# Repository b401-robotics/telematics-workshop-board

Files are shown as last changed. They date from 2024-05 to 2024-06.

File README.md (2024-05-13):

<!-- center -->
<h1 align="center">Telematics Workshop Board</h1>

<p align="center">
	</a>
	</a>
	</a>
</p>

This repository contains the documentation for the Workshop Telematics Board. The board is based on the ESP8266 microcontroller and has several features that can be used for various projects.

<!-- beritahu versi lawas -->
> For the previous version of the board, refer to the [v1 board.](https://github.com/b401-robotics/esp8266-minsys)

## 🌟 Features

The following are the features available on this board.

- ESP-12F (ESP8266)
- 8 GPIO Pins
- Programmable RGB LED
- Overcurrent Protection
- USB Type-C Connector (_Power Delivery Support_) 

## 👀 Preview

Here is a preview of the board that will be used in the workshop.

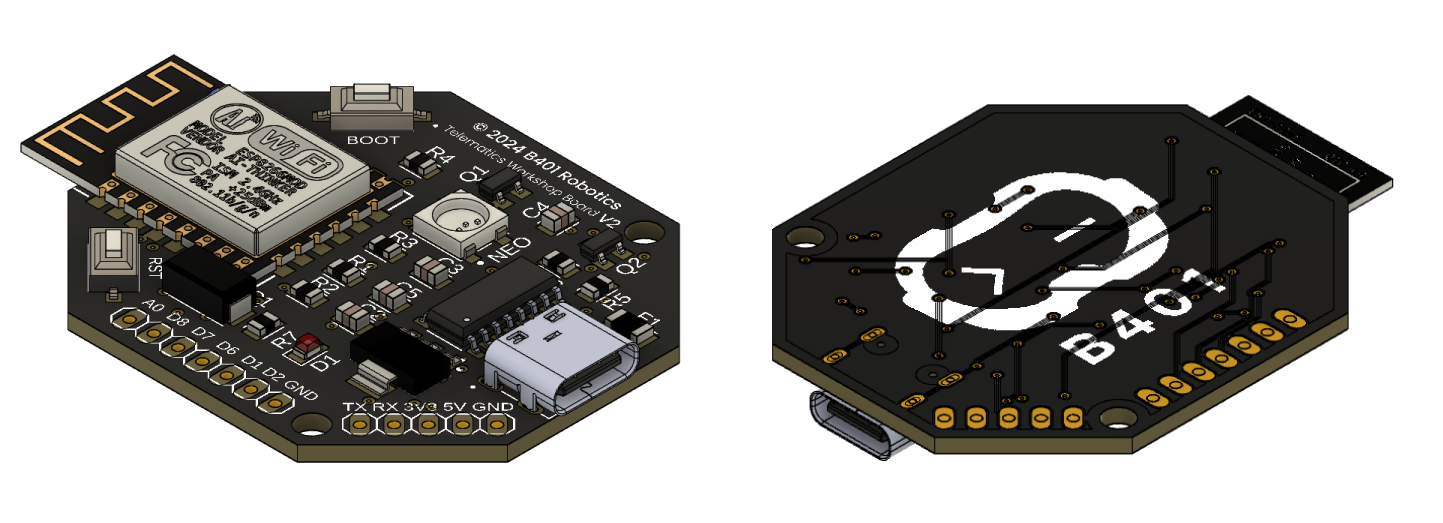
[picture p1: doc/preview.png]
Board Preview


## 📚 Resources

For more information about the board, you can check the following resources.

- [Hardware](hardware/)
- [Firmware](firmware/)

## 🔮 Project Showcase

Discover projects that use this board in various applications and contexts.

- [🌌 __COMING SOON__]() by [farisrfp](https://farisrfp.me)

## 📝 License

Distributed under the MIT License. See `LICENSE` for more information.

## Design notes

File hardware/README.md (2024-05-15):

# **Hardware**

This folder contains the hardware design for the Telematics Workshop Board.

## 🚀 Getting Started

### Prerequisites

- [Eagle](https://www.autodesk.com/products/eagle/overview) 
- [Fusion 360](https://www.autodesk.com/products/fusion-360/overview)

## 🕸 Schematic

This is the schematic diagram for the Board will be used in the workshop.

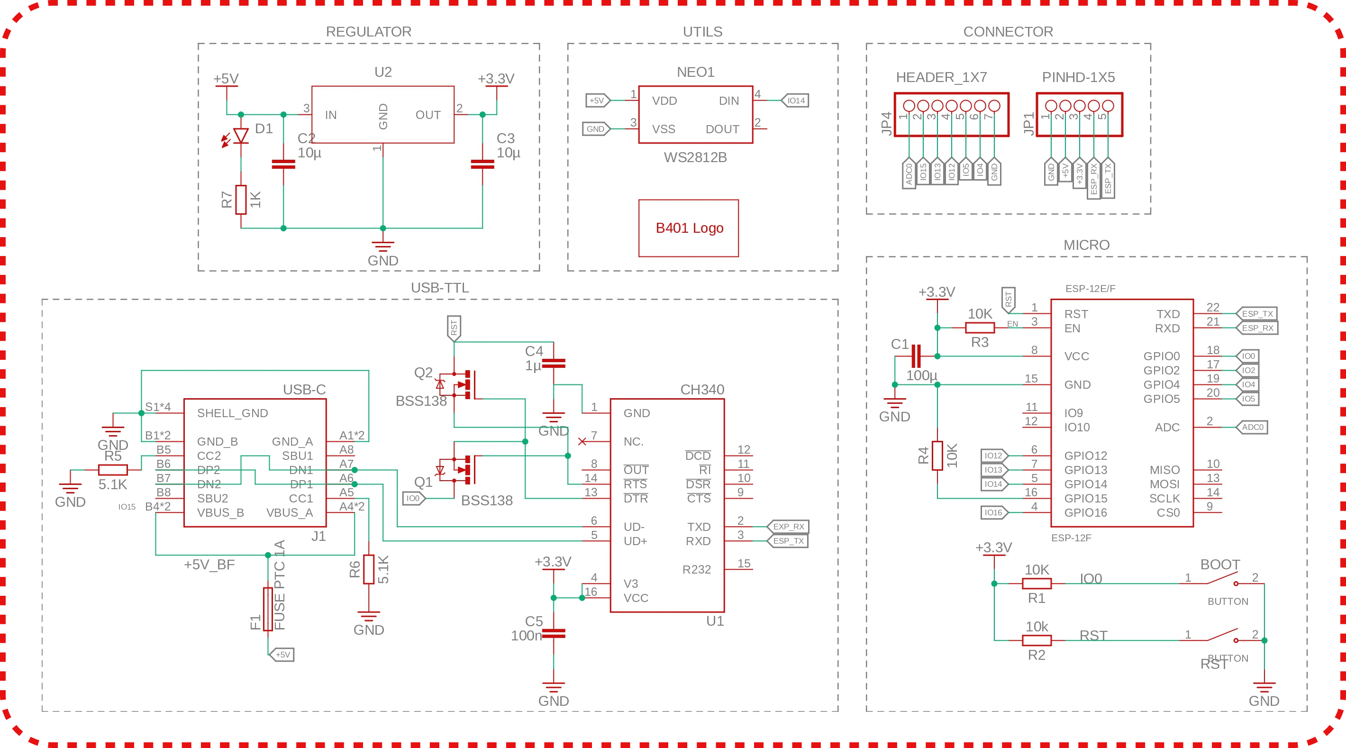
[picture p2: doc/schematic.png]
Schematic


## 💲 Bill of Material

| Designator | Quantity | Package  | Value  | Description |
|:---:|:---:|:---:|:---:|:---:|
| ESP-12F | 1 | - | - | ESP8266 Module |
| U1 | 1 |  SOP-16  | CH340C | IC USB to UART |
| U2 | 1 | SOT-223  |  3V3 | Voltage Regulator 3V3 |
| D1 | 1 | 0805 |  Red | LED |
| NEO | 1 | 5050 |  RGB | WS2812B |
| F1 | 1 | 1206 | 750mA  | Resettable Fuse |
| J1 | 1 | - |  16P | USB Type-C |
| BOOT, RST | 2 | - | - | Push Button |
| R1, R2, R3, R4 | 4 | 0805 |  10K | Resistor |
| R5, R6 | 2 | 0805 |  5.1K  | Resistor |
| R7 | 1 | 0805 | 1K | Resistor |
| C1 | 1 | 2412 |  100u  | Capacitor (Polar) |
| C2, C3 | 2 | 0805 |  10u | Capacitor (Nonpolar)  |
| C4 | 1 | 0805 | 1u | Capacitor (Nonpolar)  |
| C5 | 1 | 0805 |  10n | Capacitor (Nonpolar)  |
| Q1, Q2 | 2 |  SOT-23  | BSS138 | N-Channel MOSFET |

## 👨‍🔧 PCB Assembly

Refer to the image below for detailed placement and routing.

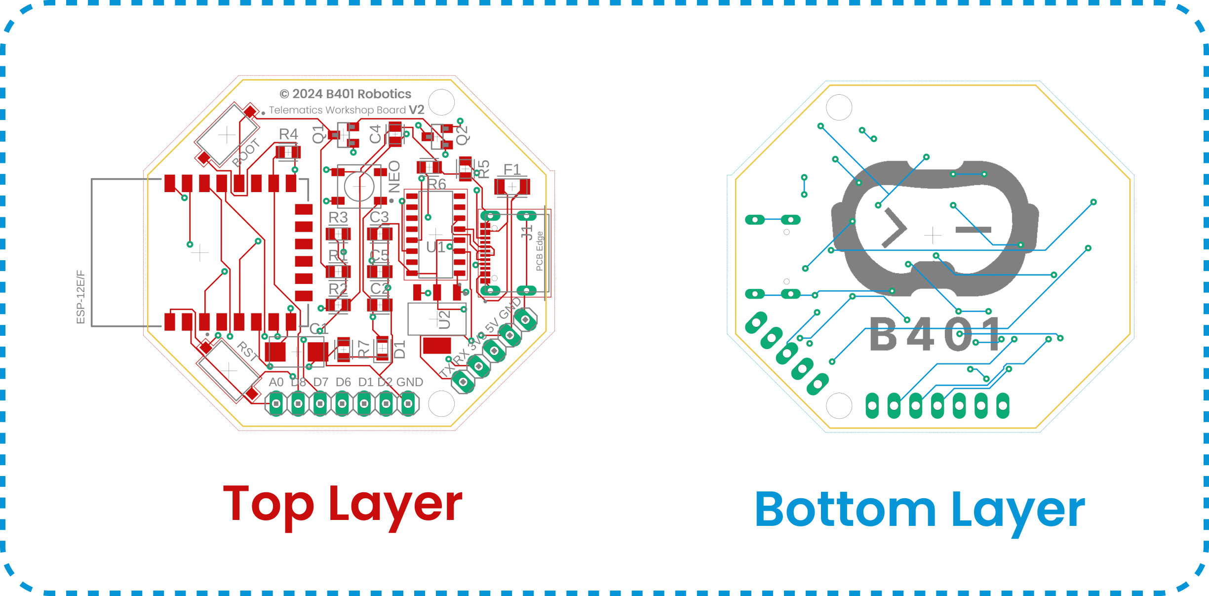
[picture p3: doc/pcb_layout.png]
PCB Layout


> Click the image to view the full resolution.

### SMD Polarity

SMD LEDs have 2 pins, namely the anode and cathode pins. Refer to the image below to determine which pin is the anode and cathode.

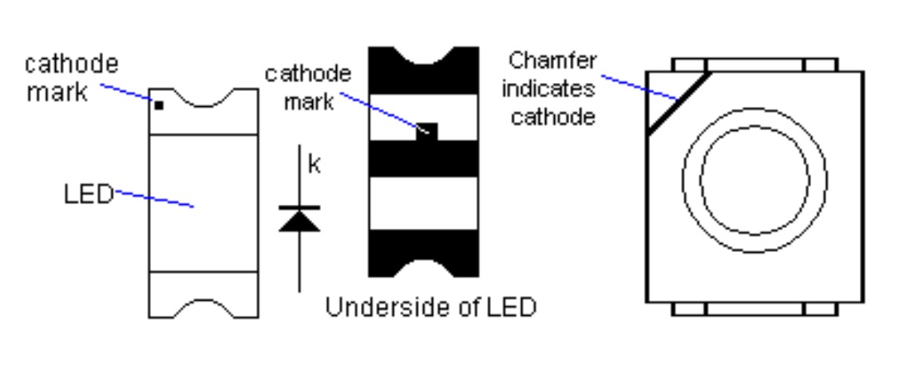
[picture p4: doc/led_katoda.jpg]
SMD Led Polarity


The Tantalum Capacitor is one of the polar capacitors. Refer to the image below to determine which pin is the anode(+).

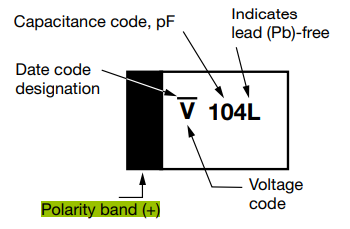
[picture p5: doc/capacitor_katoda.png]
Capacitor Tantalum Polarity


## 📚 Resources

### Telematics Workshop Board

Access the design files for the Telematics Workshop Board directly from this repository:

- [Schematic](./telematics_board_v2.sch)
- [Board Design](./telematics_board_v2.brd)
- [3D Model](./telematics_board_v2.step)
- [Eagle/Fusion 360 Library](libraries/)

### Enclosure

Access the 3D printable enclosure files from this repository, with contributions from the following individuals:

- [B401 Robotics]()

<!-- ## SMD Polarity

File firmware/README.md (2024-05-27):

# **Firmware**

This folder contains the firmware for the Telematics Workshop Board. The firmware is based on the ESP8266 microcontroller and uses the Arduino framework for development.

## 🚀 Getting Started

### Prerequisites

- [PlatformIO](https://platformio.org/)
- [Visual Studio Code](https://code.visualstudio.com/)

### Dependencies

- [💡 FastLED]()
- [👆 EasyButton]()

### Installation

1. Clone the repo
   ```sh
   git clone
   ```
2. Open the firmware folder and open the project in Visual Studio Code
   ```sh
   cd firmware
   code .
   ```
3. Build and upload the firmware to the board

##

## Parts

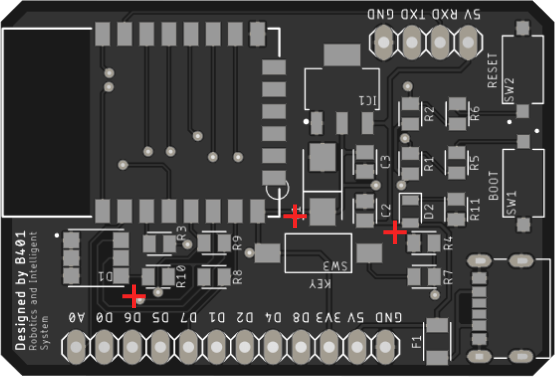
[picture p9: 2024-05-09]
doc/polar_component.png

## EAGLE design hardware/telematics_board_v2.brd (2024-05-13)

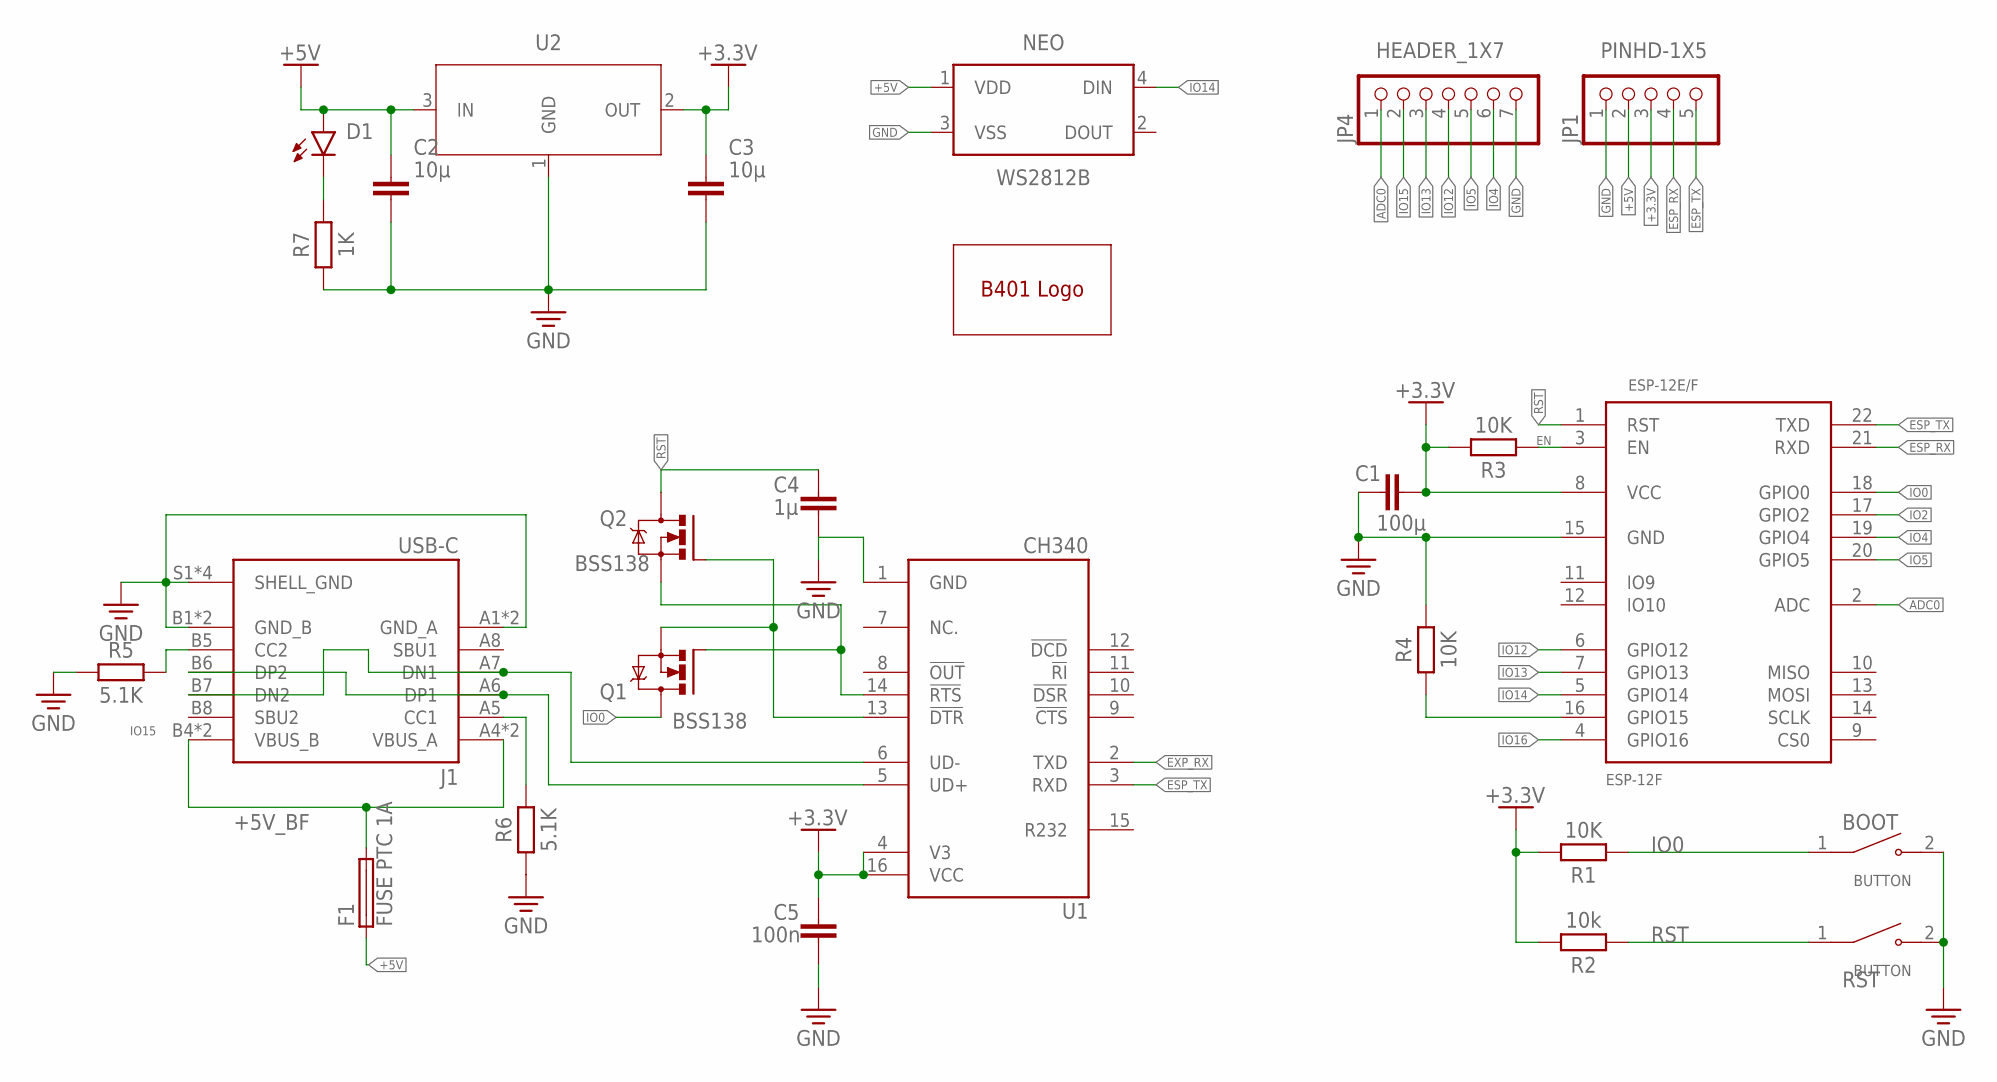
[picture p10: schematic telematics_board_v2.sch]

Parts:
BOOT: BUTTON; SWITCH-2P
C1: 100µ; CAPM6032X280
C2, C3: 10µ; CAPC2012X110
C4: 1µ; CAPC2012X110
C5: 100n; CAPC2012X110
D1: LED_RED; LEDC2012X110N_FLAT-R
ESP-12E/F: ESP-12F
F1: FUSE PTC 1A; FUSC3215X82N
J1: USB-C; USB-C-16P
JP1: PINHD-1X5; 1X05
JP4: HEADER_1X7; 1X07
NEO: WS2812B
Q1, Q2: BSS138; SOT23
R1, R3, R4: 10K; RESC2012X65
R2: 10k; RESC2012X65
R5, R6: 5.1K; RESC2012X65
R7: 1K; RESC2012X65
RST: BUTTON; SWITCH-2P
U1: CH340; SOIC127P600X180-16N
U2: NCP1117ST33T3G; SOT230P700X170-4
U$1: LOGO_B401LARGE; B401_LARGE

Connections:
+3.3V: C1.2, C3.1, C5.1, ESP-12E/F.8 (VCC), JP1.3, R1.2, R2.2, R3.2, U1.4 (V3), U1.16 (VCC), U2.2 (OUT)
+5V: C2.1, D1.A, F1.1, JP1.2, NEO.1 (VDD), U2.3 (IN)
+5V_BF: F1.2, J1.A4 (VBUS_A), J1.A9 (VBUS_A), J1.B4 (VBUS_B), J1.B9 (VBUS_B)
ADC0: ESP-12E/F.2 (ADC), JP4.1
EN: ESP-12E/F.3 (EN), R3.1
ESP_RX: ESP-12E/F.21 (RXD), JP1.4
ESP_TX: ESP-12E/F.22 (TXD), JP1.5, U1.3 (RXD)
EXP_RX: U1.2 (TXD)
GND: BOOT.2, C1.1, C2.2, C3.2, C4.2, C5.2, ESP-12E/F.15 (GND), J1.A1 (GND_A), J1.A12 (GND_A), J1.B1 (GND_B), J1.B12 (GND_B), J1.S1 (SHELL_GND), J1.S2 (SHELL_GND), J1.S3 (SHELL_GND), J1.S4 (SHELL_GND), JP1.1, JP4.7, NEO.3 (VSS), R4.2, R5.1, R6.1, R7.1, RST.2, U1.1 (GND), U2.1 (GND)
IO0: BOOT.1, ESP-12E/F.18 (GPIO0), Q1.3 (D), R1.1
IO2: ESP-12E/F.17 (GPIO2)
IO4: ESP-12E/F.19 (GPIO4), JP4.6
IO5: ESP-12E/F.20 (GPIO5), JP4.5
IO12: ESP-12E/F.6 (GPIO12), JP4.4
IO13: ESP-12E/F.7 (GPIO13), JP4.3
IO14: ESP-12E/F.5 (GPIO14), NEO.4 (DIN)
IO15: ESP-12E/F.16 (GPIO15), JP4.2, R4.1
IO16: ESP-12E/F.4 (GPIO16)
unnamed: J1.A6 (DP1), J1.B6 (DP2), U1.5 (UD+)
unnamed: J1.A7 (DN1), J1.B7 (DN2), U1.6 (UD-)
unnamed: Q1.2 (S), Q2.1 (G), U1.13 (!DTR)
unnamed: J1.B5 (CC2), R5.2
unnamed: J1.A5 (CC1), R6.2
unnamed: Q1.1 (G), Q2.2 (S), U1.14 (!RTS)
unnamed: D1.C, R7.2
RST: C4.1, ESP-12E/F.1 (RST), Q2.3 (D), R2.1, RST.1

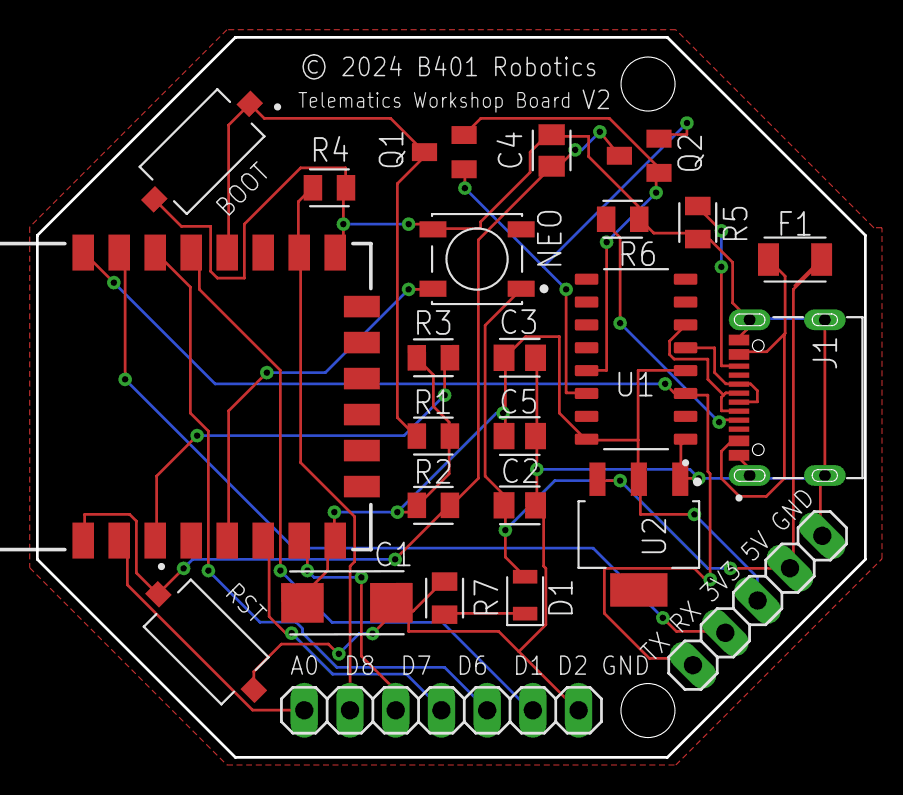
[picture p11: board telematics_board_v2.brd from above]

Board: 2 copper layers, 46.0 x 40.0 mm, 26 parts (1 on the bottom side), 23 nets.

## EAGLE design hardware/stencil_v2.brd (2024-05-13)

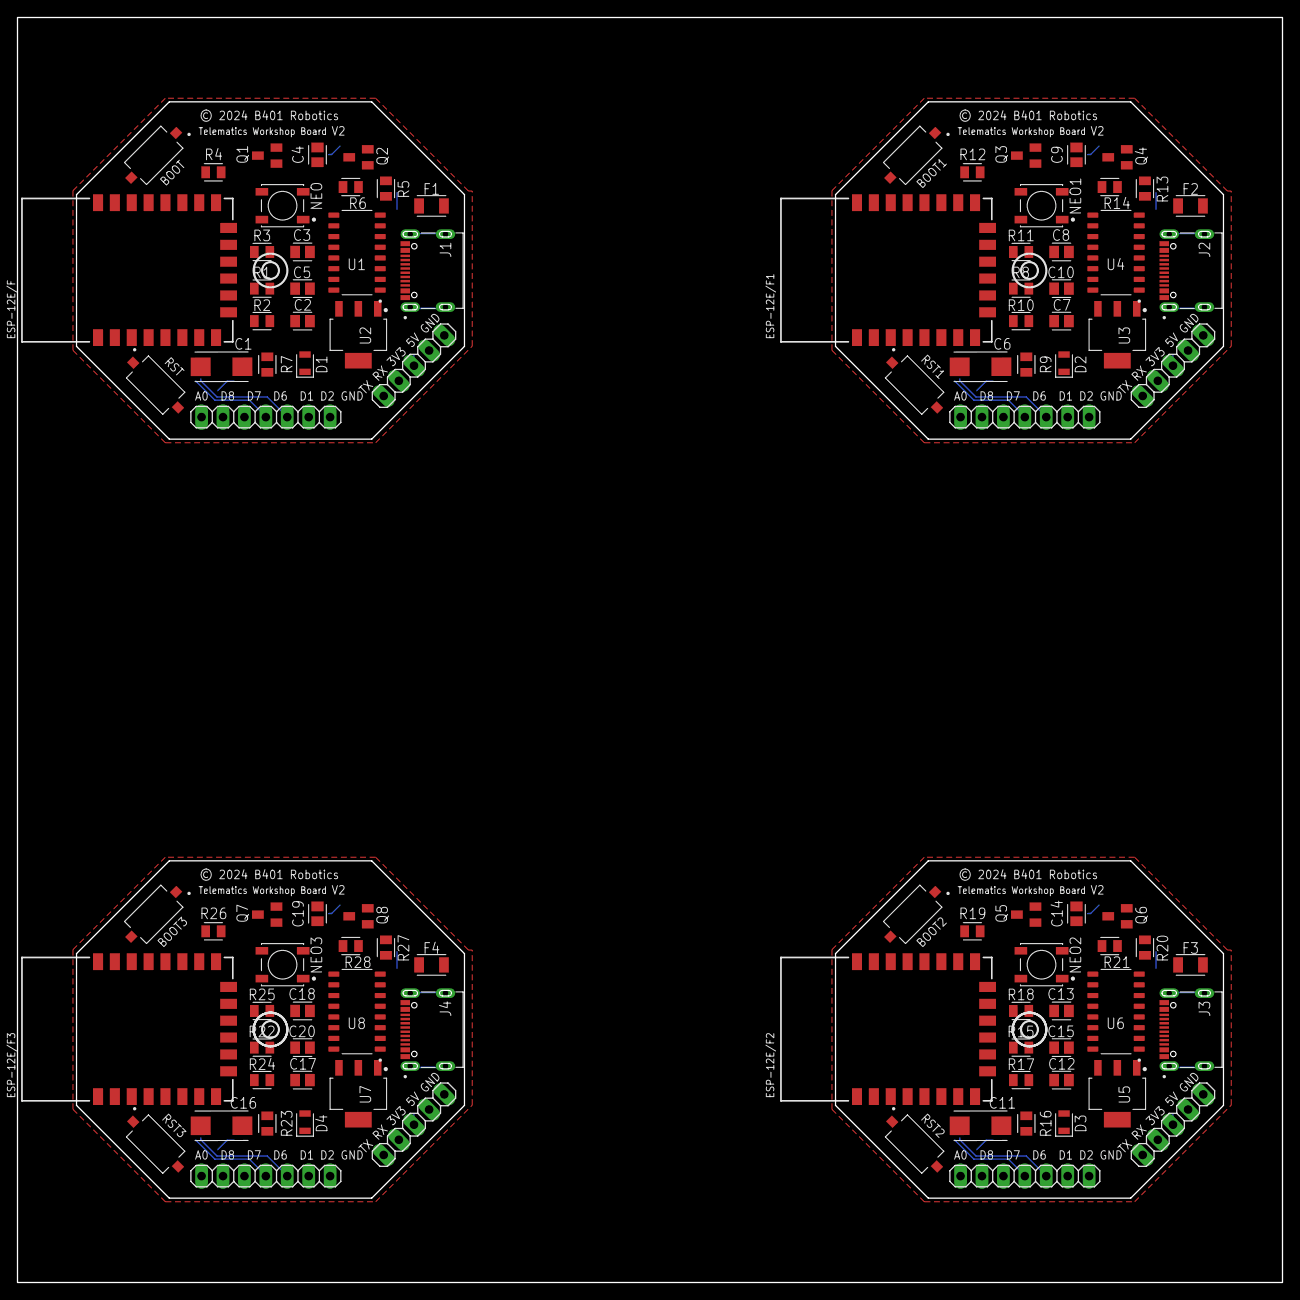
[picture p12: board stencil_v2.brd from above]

Board: 2 copper layers, 150.0 x 150.0 mm, 100 parts (0 on the bottom side), 88 nets.

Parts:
BOOT, BOOT1, BOOT2, BOOT3: BUTTON; SWITCH-2P
C1, C6, C11, C16: 100µ; CAPM6032X280
C2, C3, C7, C8, C12, C13, C17, C18: 10µ; CAPC2012X110
C4, C9, C14, C19: 1µ; CAPC2012X110
C5, C10, C15, C20: 100n; CAPC2012X110
D1, D2, D3, D4: LED_RED; LEDC2012X110N_FLAT-R
ESP-12E/F, ESP-12E/F1, ESP-12E/F2, ESP-12E/F3: ESP-12F
F1, F2, F3, F4: FUSE PTC 1A; FUSC3215X82N
J1, J2, J3, J4: USB-C; USB-C-16P
JP1, JP3, JP6, JP8: PINHD-1X5; 1X05
JP2, JP4, JP5, JP7: HEADER_1X7; 1X07
NEO, NEO1, NEO2, NEO3: WS2812B
Q1, Q2, Q3, Q4, Q5, Q6, Q7, Q8: BSS138; SOT23
R1, R3, R4, R8, R11, R12, R15, R18, R19, R22, R25, R26: 10K; RESC2012X65
R2, R10, R17, R24: 10k; RESC2012X65
R5, R6, R13, R14, R20, R21, R27, R28: 5.1K; RESC2012X65
R7, R9, R16, R23: 1K; RESC2012X65
RST, RST1, RST2, RST3: BUTTON; SWITCH-2P
U1, U4, U6, U8: CH340; SOIC127P600X180-16N
U2, U3, U5, U7: NCP1117ST33T3G; SOT230P700X170-4

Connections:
+3.3V: C3.1, C5.1, U1.4, U1.16, U2.2
+3.3V1: C8.1, C10.1, U3.2, U4.4, U4.16
+3.3V2: C13.1, C15.1, U5.2, U6.4, U6.16
+3.3V3: C18.1, C20.1, U7.2, U8.4, U8.16
+5V: F1.1, JP1.2
+5V1: F2.1, JP3.2
+5V2: F3.1, JP6.2
+5V3: F4.1, JP8.2
+5V_BF: F1.2, J1.A4, J1.A9, J1.B4, J1.B9
+5V_BF1: F2.2, J2.A4, J2.A9, J2.B4, J2.B9
+5V_BF2: F3.2, J3.A4, J3.A9, J3.B4, J3.B9
+5V_BF3: F4.2, J4.A4, J4.A9, J4.B4, J4.B9
ADC0: ESP-12E/F.2, JP4.1
ADC1: ESP-12E/F1.2, JP2.1
ADC2: ESP-12E/F2.2, JP5.1
ADC3: ESP-12E/F3.2, JP7.1
ESP_TX: JP1.5, U1.3
ESP_TX1: JP3.5, U4.3
ESP_TX2: JP6.5, U6.3
ESP_TX3: JP8.5, U8.3
GND: C4.2, J1.A1, J1.A12, J1.B1, J1.B12, J1.S1, J1.S2, J1.S3, J1.S4, JP1.1, NEO.3, R5.1, R6.1
GND1: C9.2, J2.A1, J2.A12, J2.B1, J2.B12, J2.S1, J2.S2, J2.S3, J2.S4, JP3.1, NEO1.3, R13.1, R14.1
GND2: C14.2, J3.A1, J3.A12, J3.B1, J3.B12, J3.S1, J3.S2, J3.S3, J3.S4, JP6.1, NEO2.3, R20.1, R21.1
GND3: C19.2, J4.A1, J4.A12, J4.B1, J4.B12, J4.S1, J4.S2, J4.S3, J4.S4, JP8.1, NEO3.3, R27.1, R28.1
IO0: BOOT.1, ESP-12E/F.18, Q1.3, R1.1
IO1: BOOT1.1, ESP-12E/F1.18, Q3.3, R8.1
IO3: ESP-12E/F1.6, JP2.4
IO12: ESP-12E/F.6, JP4.4
IO15: ESP-12E/F.16, JP4.2, R4.1
IO17: ESP-12E/F1.16, JP2.2, R12.1
IO18: BOOT2.1, ESP-12E/F2.18, Q5.3, R15.1
IO19: ESP-12E/F2.6, JP5.4
IO26: ESP-12E/F2.16, JP5.2, R19.1
IO27: BOOT3.1, ESP-12E/F3.18, Q7.3, R22.1
IO28: ESP-12E/F3.6, JP7.4
IO35: ESP-12E/F3.16, JP7.2, R26.1
unnamed: J1.A6, J1.B6, U1.5
unnamed: J1.A7, J1.B7, U1.6
unnamed: Q1.2, Q2.1
unnamed: J1.B5, R5.2
unnamed: D1.C, R7.2
unnamed: D2.C, R9.2
unnamed: J2.A6, J2.B6, U4.5
unnamed: J2.A7, J2.B7, U4.6
unnamed: Q3.2, Q4.1
unnamed: J2.B5, R13.2
unnamed: D3.C, R16.2
unnamed: J3.A6, J3.B6, U6.5
unnamed: J3.A7, J3.B7, U6.6
unnamed: Q5.2, Q6.1
unnamed: J3.B5, R20.2
unnamed: D4.C, R23.2
unnamed: J4.A6, J4.B6, U8.5
unnamed: J4.A7, J4.B7, U8.6
unnamed: Q7.2, Q8.1
unnamed: J4.B5, R27.2
RST: C4.1, Q2.3, R2.1
RST1: C9.1, Q4.3, R10.1
RST2: C14.1, Q6.3, R17.1
RST3: C19.1, Q8.3, R24.1
S$1: C1.2, ESP-12E/F.8
S$2: R1.2, R2.2, R3.2
S$4: C1.1, C2.2, C3.2, C5.2, JP4.7, R7.1, RST.2
S$5: U1.1, U2.1
S$6: BOOT.2, ESP-12E/F.15, R4.2
S$7: ESP-12E/F.1, RST.1
S$11: C2.1, D1.A, NEO.1
S$21: C6.2, ESP-12E/F1.8
S$22: R8.2, R10.2, R11.2
S$24: U3.1, U4.1
S$25: C6.1, C7.2, C8.2, C10.2, JP2.7, R9.1, RST1.2
S$26: BOOT1.2, ESP-12E/F1.15, R12.2
S$27: ESP-12E/F1.1, RST1.1
S$32: C7.1, D2.A, NEO1.1
S$41: C11.2, ESP-12E/F2.8
S$42: R15.2, R17.2, R18.2
S$44: U5.1, U6.1
S$45: C11.1, C12.2, C13.2, C15.2, JP5.7, R16.1, RST2.2
S$46: BOOT2.2, ESP-12E/F2.15, R19.2
S$47: ESP-12E/F2.1, RST2.1
S$52: C12.1, D3.A, NEO2.1
S$61: C16.2, ESP-12E/F3.8
S$62: R22.2, R24.2, R25.2
S$64: U7.1, U8.1
S$65: C16.1, C17.2, C18.2, C20.2, JP7.7, R23.1, RST3.2
S$66: BOOT3.2, ESP-12E/F3.15, R26.2
S$67: ESP-12E/F3.1, RST3.1
S$72: C17.1, D4.A, NEO3.1

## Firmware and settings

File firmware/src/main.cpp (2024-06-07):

/*
☲☲☲☲ GETTING STARTED CODE ☲☲☲☲

- This code is for Wortel Development Board V2.
- This code is for beginners who want to learn how to program Wortel Development Board.
- And guess what? It's compatible with both PlatformIO and Arduino IDE!
*/

#include <Arduino.h>     // Standard Arduino library
#include <EasyButton.h>  // Library for handling button press
#include <FastLED.h>     // Library for controlling RGB LED

/* Variable Declaration */
#define BUTTON_PIN 0  // Button Pin
#define LED_PIN D5    // RGB LED Pin
#define NUM_LEDS 1    // Number of RGB LED

CRGB leds[NUM_LEDS];            // RGB LED Array
EasyButton button(BUTTON_PIN);  // Button Object

/* Function Prototype */
void buttonPressed();        // Function to handle button press
void buttonLongPressed();    // Function to handle long press
void buttonDoubleClicked();  // Function to handle double click
void buttonTripleClicked();  // Function to handle triple click

void setup() {
    /* Initialize Serial Monitor */
    Serial.begin(115200);
    randomSeed(analogRead(A0));

    /* Initialize RGB LED */
    FastLED.addLeds<WS2812, LED_PIN, GRB>(leds, NUM_LEDS);

    /* Initialize Button */
    button.begin();
    button.onPressed(buttonPressed);
    button.onPressedFor(500, buttonLongPressed);
    button.onSequence(2, 500, buttonDoubleClicked);
    button.onSequence(3, 500, buttonTripleClicked);

    /* you can add your code here */
}

void loop() {
    button.read();  // Always read the button in the loop

    /* you can add your code here */
}

void buttonPressed() {
    Serial.printf("Button Pressed\n");

    /* Generate Random Color */
    leds[0] = CRGB(random(126), random(126), random(126));
    FastLED.show();
}

void buttonLongPressed() {
    Serial.printf("Button Long Pressed\n");

    leds[0] = CRGB::Red;
    FastLED.show();
}

void buttonDoubleClicked() {
    Serial.printf("Button Double Clicked\n");

    leds[0] = CRGB::Green;
    FastLED.show();
}

void buttonTripleClicked() {
    Serial.printf("Button Triple Clicked\n");

    leds[0] = CRGB::Black;
    FastLED.show();
}

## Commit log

2024-05-13 chore: Update board name and fix typos in README files
2024-05-13 doc: add missing file
    [board.brd, board.sch, stencil.brd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]
2024-05-14 fix readme di hardware ada yg salah
2024-05-27 chore: Update board name, fix typos, and add missing file in README files
    [main.cpp]
2024-06-07 Update LED pin and serial baud rate, and generate random color with reduced intensity
2024-06-07 fix baudrate di platform.ini & tambah fungsi utk mematikan rgb led
    [main.cpp]

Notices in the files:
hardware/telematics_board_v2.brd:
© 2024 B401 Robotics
